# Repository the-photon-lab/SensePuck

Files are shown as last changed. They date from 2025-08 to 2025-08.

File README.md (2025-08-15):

# SensePuck / ESP32-C6 Sensor Board

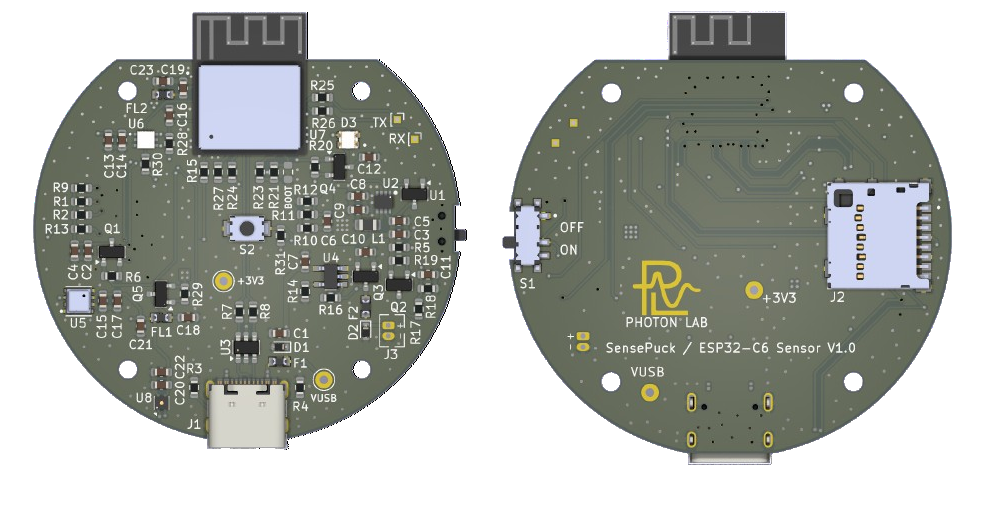
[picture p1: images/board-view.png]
SensePuck Board


**SensePuck is a compact, open-source environmental sensor board built around the ESP32-C6.** It's designed for a wide range of applications, from personal weather stations and air quality monitors to IoT data-logging projects.

---

## Key Features

-   **MCU:** **ESP32-C6-MINI-1-N4** providing Wi-Fi 6, Bluetooth 5 (LE), Zigbee, and Thread connectivity.
-   **Environmental Sensing:**
    -   **BME688:** Measures temperature, humidity, barometric pressure, and gas (Volatile Organic Compounds - VOCs).
    -   **SHT40:** High-accuracy secondary sensor for temperature and humidity.
    -   **LTR-390UV-01:** Measures both ambient light and UVA/UVB (UV Index). Includes an interrupt output for event-driven wake-ups.
-   **Flexible Power Management:**
    -   **USB-C** for charging and programming.
    -   **LiPo Battery Charger** (MCP73831T).
    -   High-efficiency **3.3V Buck Converter** (TPS62821DLCR).
    -   Physical **On/Off Power Switch**.
-   **Onboard Data Storage:** **MicroSD card slot** with card-detect switch.
-   **User Interface:**
    -   **WS2812B "NeoPixel" RGB LED** for status indication.
    -   **User-programmable tactile button**.
-   **Developer Friendly:**
    -   ESP32 Native USB connection for easy programming.
    -   Dedicated pins for initial bring-up (BOOT pins) and UART (TX/RX) for debugging.

---

## Hardware Details

The SensePuck is designed with low-power operation as a primary goal, making it ideal for long-term battery-powered deployments. This is achieved through a combination of a high-efficiency power supply, aggressive power gating of all major peripherals, and measurement circuits.

### Power Supply and Battery Management

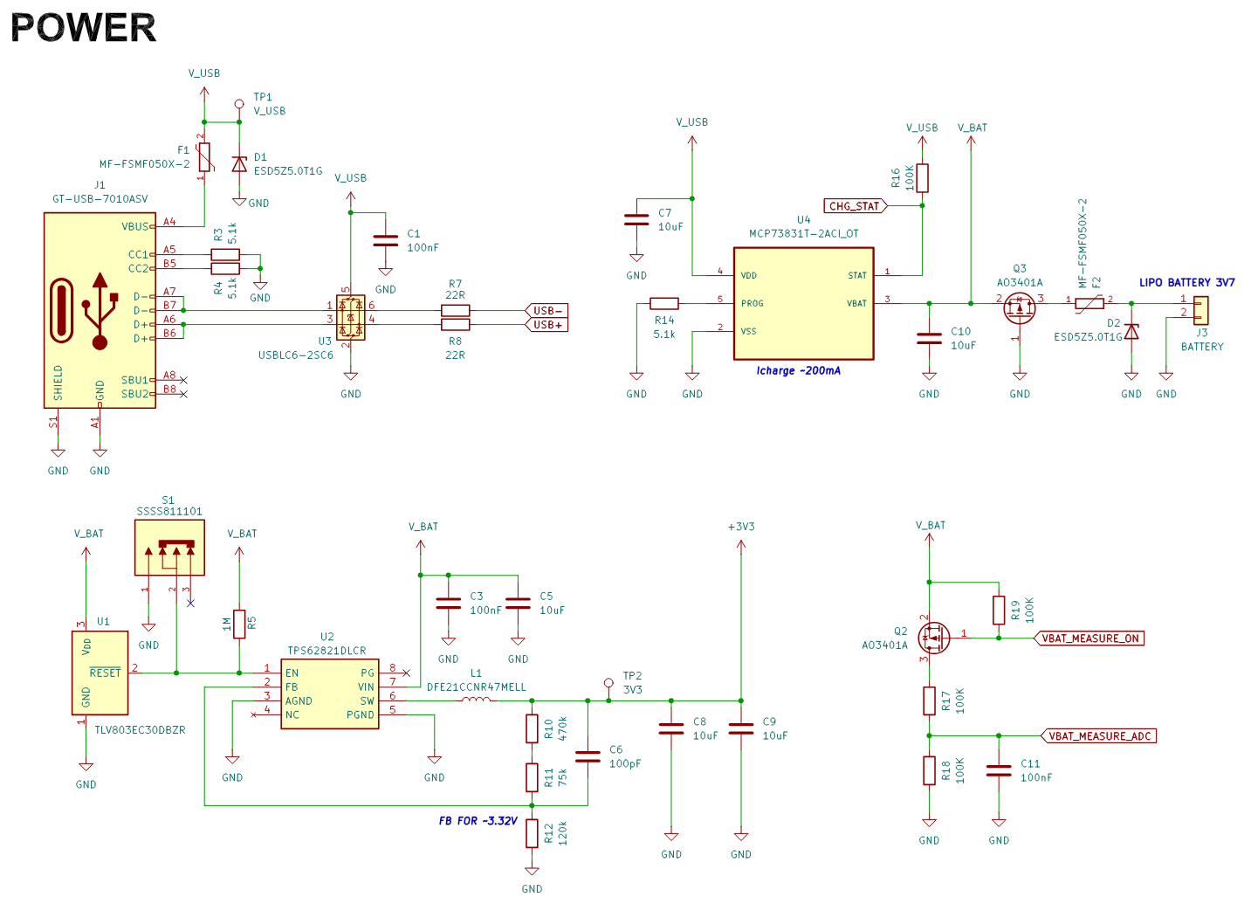
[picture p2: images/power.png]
Power Circuit


The power section is designed for efficiency, reliability, and safety in long-term battery-powered applications.

*   **Power Source:** The board is designed to be powered by a standard 3.7V single-cell LiPo battery. A physical **slide switch (S1)** serves as the master On/Off control by controlling the `ENABLE` pin of the TPS62821DLCR buck converter. For development and charging, it uses a **USB-C connector (J1)**. The USB input is protected by a **resettable fuse (F1)** and **ESD protection diodes (U3, D1)** to guard against overcurrent and electrical discharge events.

*   **Battery Charging:** The **MCP73831T (U4)** is a dedicated LiPo/Li-Ion charge management controller IC that provides reliable single-cell charging. The charge current is set to ~200mA via resistor **R14**, a conservative value suitable for a wide range of small LiPo batteries. A P-Channel MOSFET **(Q3)** provides reverse-polarity protection for the battery. The MCU can monitor the charging state (`Charging`/`Done`) via the `CHG_STAT` pin.

*   **Voltage Regulation:** The main 3.3V power supply is based on the **TPS62821DLCR (U2)**, a high-efficiency synchronous buck (step-down) converter. It takes the battery voltage and generates a stable 3.3V supply for the ESP32 and all peripherals. It offers an **extremely low quiescent current of just 60nA**, which is the tiny amount of power it consumes just by being on. This power consumption helps in achieving multi-week or multi-month battery life when the ESP32 is in deep sleep.

*   **Hardware Failsafe:** A common failure point in battery-powered devices is unstable operation when the battery voltage drops. As the battery voltage falls below 3.3V, a standard buck converter enters "dropout mode," where it can no longer regulate, and the output voltage sags along with the battery. This can cause the ESP32 to enter a "brownout" state, leading to unpredictable resets, corrupted data on the SD card, or a boot-loop that quickly kills the battery.

    To prevent this, SensePuck incorporates a **TLV803EC30DBZR (U1) voltage supervisor**.
    *   It **independently** monitors the battery voltage, completely separate from the MCU, and consumes only ~0.4µA.
    *   If the voltage drops below its fixed threshold of ~3V, the supervisor **immediately and automatically disables the buck converter** by pulling its `EN` (Enable) pin low.
    *   This forces a **clean, hard shutdown**, preventing the entire system from operating with an unstable power supply. It also serves as the main protection against over-discharging and permanently damaging the battery, even if the main firmware has crashed.

This hardware-based approach is more reliable than a software-only voltage check, which cannot prevent brownouts caused by sudden current spikes (e.g., Wi-Fi activation) or protect the battery if the software hangs.

---

### Power Gating

To achieve the lowest possible sleep current, all peripherals are completely powered off. The SensePuck uses P-Channel MOSFETs as high-side switches to disconnect power from entire circuit sections.

#### Sensor Power Control

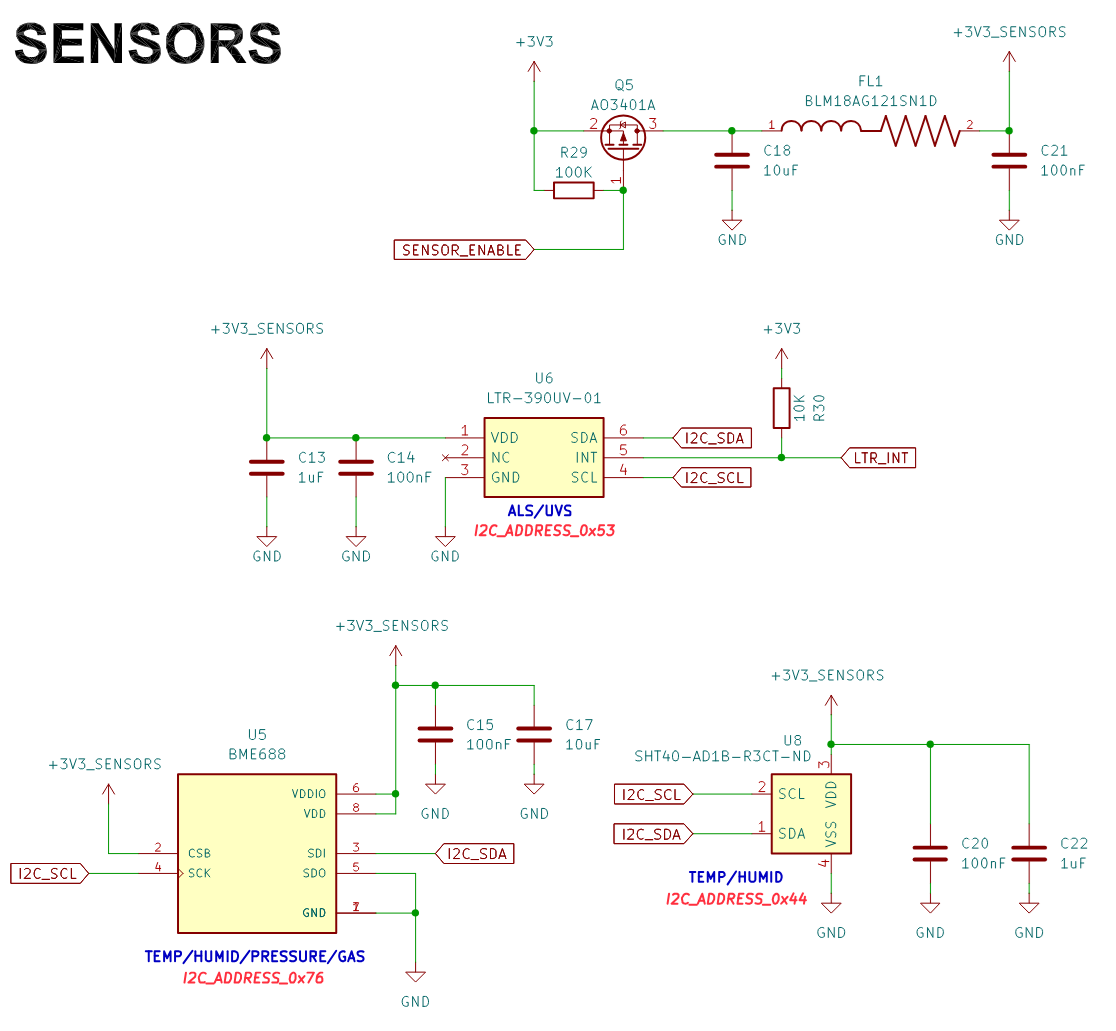
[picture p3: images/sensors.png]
Sensor Power Gating


The BME688, SHT40, and LTR-390UV sensors, while low-power, still have a quiescent current draw that would drain the battery over a few days.

*   **The Switch:** A single **P-Channel MOSFET (Q5)** controls the power rail (`+3V3_SENSORS`) for all three sensors.
*   **The Control:** The MCU's `SENSOR_ENABLE` GPIO pin controls this MOSFET.
    *   When the MCU needs to take a reading, it pulls `SENSOR_ENABLE` **LOW**. This turns the MOSFET ON, supplying power to the sensors.
    *   After the reading is complete, the MCU sets `SENSOR_ENABLE` **HIGH**. This turns the MOSFET OFF, completely cutting power to the sensors and eliminating their idle current draw.
*   **Clean Power:** A **ferrite bead (FL1)** and capacitors create a pi filter which provides extra filtering to ensure the sensors receive clean power when they are enabled, which is important for accurate measurements.

#### SD Card and RGB LED Power Control

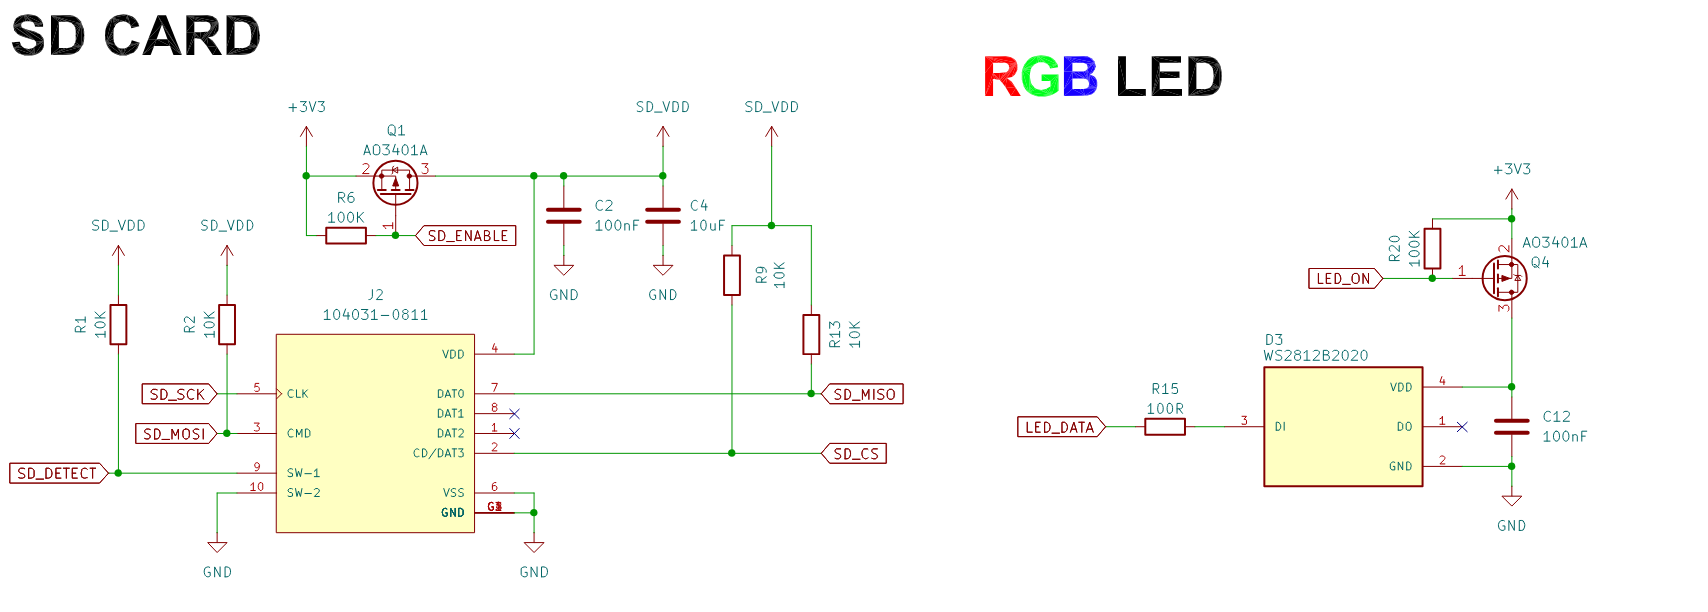
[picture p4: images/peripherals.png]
Peripheral Power Gating


This same power-gating principle is applied to the other major peripherals:

*   **SD Card:** MicroSD cards can consume significant current, even when idle. **MOSFET Q1**, controlled by the `SD_ENABLE` pin, allows the firmware to completely power down the SD card between read/write operations. The firmware can also detect if a card is present via the `SD_DETECT` pin.
*   **RGB LED:** Even the small quiescent current of the **WS2812B2020 LED (D3)** is eliminated. **MOSFET Q4**, controlled by the `LED_ON` pin, ensures the LED only receives power when it is actively being used for status indication. A 100-ohm series resistor (R15) is included to protect the data input pin and improve signal integrity.

---

### MCU and Measurement Circuits

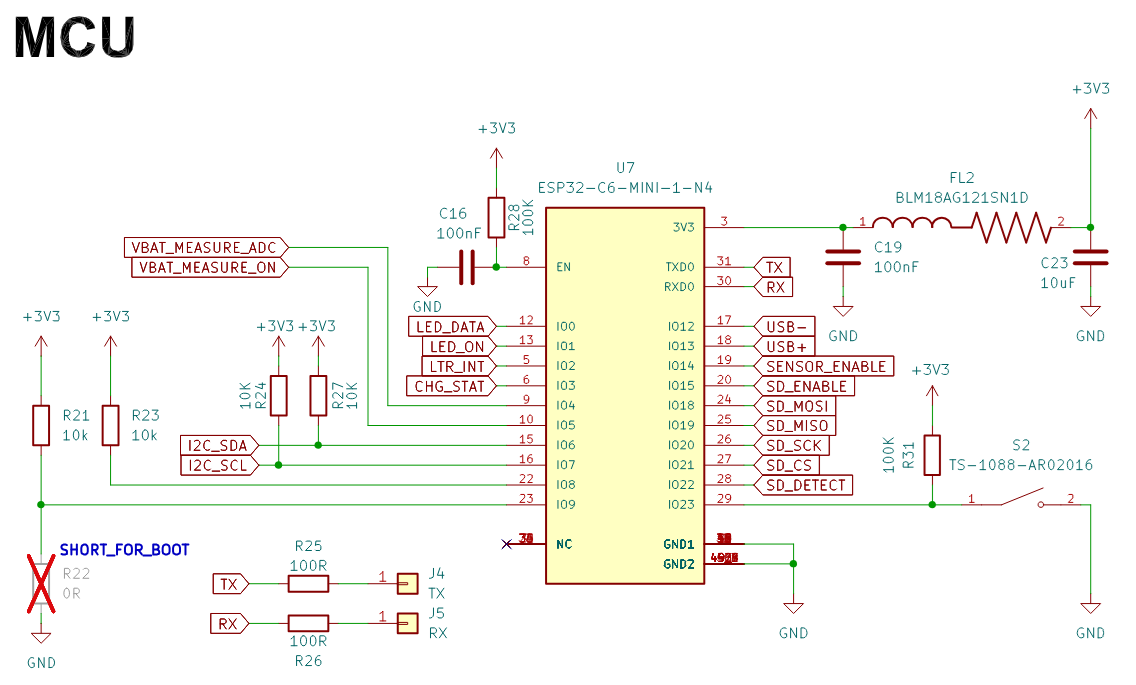
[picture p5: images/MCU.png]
MCU and Measurement Circuit


*   **ESP32-C6:** The ESP32-C6-Mini-1 is the "brain" of the board. Its primary low-power feature is its ultra deep-sleep mode, where the main cores and most peripherals are shut down, allowing the chip to run on mere microamps of current while waiting for a timer or external trigger to wake up. Its power supply is further stabilized with a dedicated ferrite bead filter (FL2).
*   **Power-Gated Battery Measurement:** Measuring the battery level without constantly draining it is a common challenge. SensePuck solves this with the following circuit:
    1.  A voltage divider (**R17** and **R18**) is used to scale the battery voltage down to a level that is safe for the ESP32's ADC.
    2.  Crucially, this divider is **not** permanently connected to the battery. A **MOSFET (Q2)** acts as a switch at the top of the divider.
    3.  To check the battery, the firmware momentarily pulls the `VBAT_MEASURE_ON` pin low, which turns on Q2, completes the circuit, and allows for an ADC reading. It then immediately turns Q2 off.
    4.  This ensures the voltage divider only draws current for the few milliseconds required to take a measurement, making the process extremely energy efficient.

---

### Component & Pinout Overview

#### Key Components

| Reference | Component | Description | I2C Address |
| :--- | :--- | :--- | :--- |
| U7 | ESP32-C6-MINI-1-N4 | Main Microcontroller with Wi-Fi 6, BT5, Zigbee, Thread | - |
| U5 | BME688 | Temperature, Humidity, Pressure & Gas (VOC) Sensor | `0x76` |
| U8 | SHT40-AD1B-R3CT-ND | High-Precision Temperature & Humidity Sensor | `0x44` |
| U6 | LTR-390UV-01 | Ambient Light & UV Sensor | `0x53` |
| U4 | MCP73831T-2ACI_OT | Li-Ion/Li-Polymer Battery Charge Management Controller | - |
| U2 | TPS62821DLCR | High-Efficiency 3.3V Step-Down Converter | - |
| J2 | 104031-0811 | MicroSD Card Socket | - |
| D3 | WS2812B2020 | Addressable RGB LED for status indication | - |

#### ESP32-C6 Pinout

| ESP32-C6 Pin | GPIO | Function | Schematic Net Name | Notes |
| :--- | :--- | :--- | :--- | :--- |
| 12 | IO0  | LED Data | `LED_DATA` | Data line for WS2812B RGB LED |
| 13 | IO1  | LED Power Enable | `LED_ON` | `LOW` = On, `HIGH` = Off |
| 5 | IO2  | LTR-390UV Interrupt | `LTR_INT` | Active-low interrupt from light sensor |
| 6 | IO3  | Charger Status Read | `CHG_STAT` | `LOW` = Charging, `HIGH`/`Z` = Done |
| 9 | IO4  | Battery Measurement ADC | `VBAT_MEASURE_ADC` | ADC input for battery voltage |
| 10 | IO5  | Battery Measurement Enable  | `VBAT_MEASURE_ON` | `LOW` = On, `HIGH` = Off |
| 15 | IO6  | I2C Data | `I2C_SDA` | Sensor I2C Bus |
| 16 | IO7  | I2C Clock | `I2C_SCL` | Sensor I2C Bus |
| 23 | IO9  | User Button / Boot | - | General purpose button |
| 19 | IO14 | Sensor Power Enable | `SENSOR_ENABLE` | `LOW` = On, `HIGH` = Off |
| 20 | IO15 | SD Card Power Enable | `SD_ENABLE` | `LOW` = On, `HIGH` = Off |
| 24 | IO18 | SPI MOSI for SD Card | `SD_MOSI` | |
| 25 | IO19 | SPI MISO for SD Card | `SD_MISO` | |
| 26 | IO20 | SPI Clock for SD Card | `SD_SCK` | |
| 27 | IO21 | SPI Chip Select for SD Card | `SD_CS` | |
| 28 | IO22 | SD Card Detect | `SD_DETECT` | `LOW` when card is inserted |

---

## Firmware

**Coming Soon!**

The firmware for the SensePuck is currently under development. It will be built using the ESP-IDF framework for complete control of the MCU's peripherals to ensure ultra-low power operation.

### Board Bring-Up

*   **Entering Bootloader Mode:** To flash the board for the first time, you must put the ESP32-C6 into bootloader mode. Short circuit the **BOOT** pads, connect the USB-C cable, and then release.
*   **Debugging:** The headers J4 (TX) and J5 (RX) expose the ESP32-C6's primary hardware UART. This can be used with an external USB-to-Serial adapter for low-level debugging.

This board is also compatible with ESPHome. YAML Configuration will be provided soon.

---

## License

This project is open source hardware, licensed under the **CERN Open Hardware Licence Version 2 - Permissive (CERN-OHL-P v2)**.

You are welcome to use, modify, manufacture, and distribute this hardware design, provided you give credit to the original author and include the original copyright and license notice. For the full license details, please see the `LICENSE` file included in this repository.

A `NOTICE` file with licensor and project details is also included, as required by the license.

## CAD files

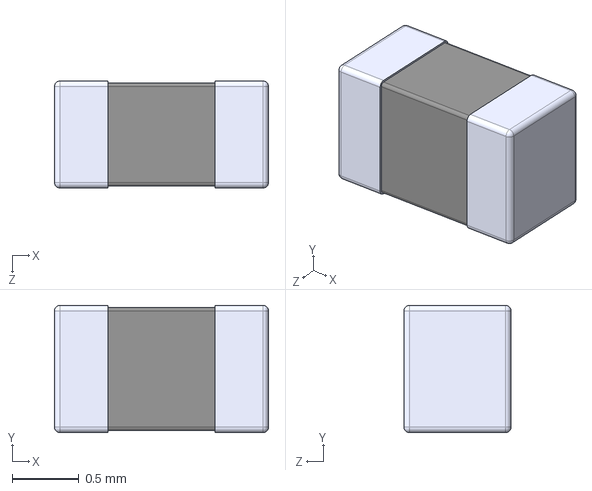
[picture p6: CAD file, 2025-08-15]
libraries-zips/BLM18AG121SN1D/BLM18AG121SN1D.step
1.60 x 0.95 x 0.8 mm

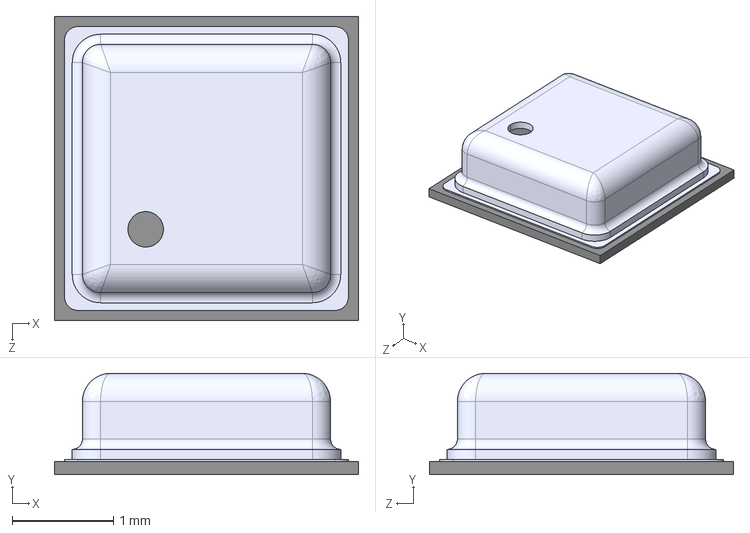
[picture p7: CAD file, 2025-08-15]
libraries-zips/BME688/BME688.step
3.00 x 1.00 x 3.00 mm

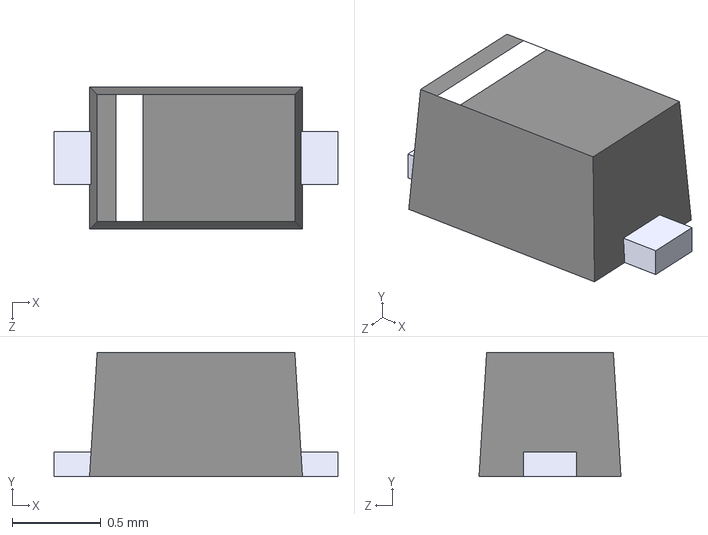
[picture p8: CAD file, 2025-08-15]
libraries-zips/ESD5Z5.0T1G/ESD5Z5.0T1G.step
1.60 x 0.7 x 0.8 mm

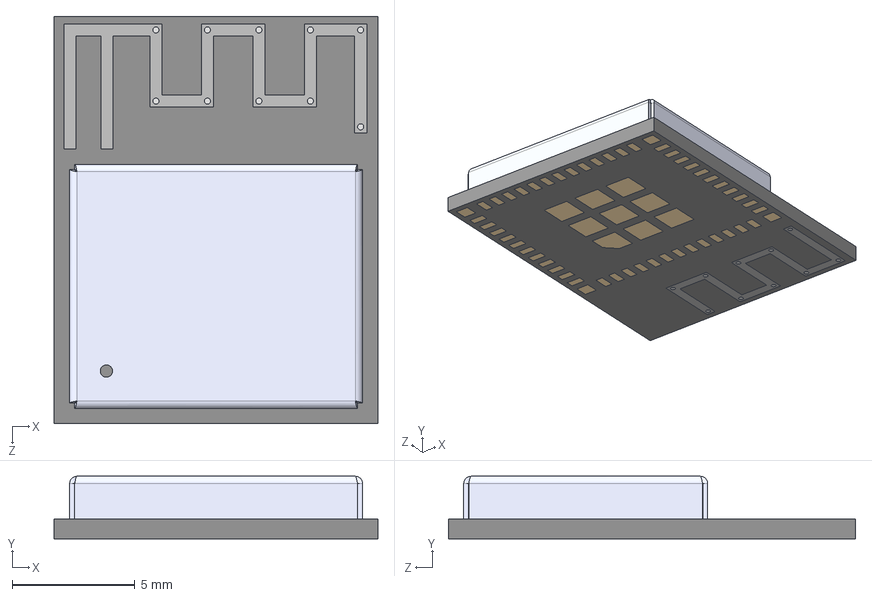
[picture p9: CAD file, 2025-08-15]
libraries-zips/ESP32-C6-MINI-1-N4/ESP32-C6-MINI-1-N4.STEP
13.2 x 2.55 x 16.6 mm

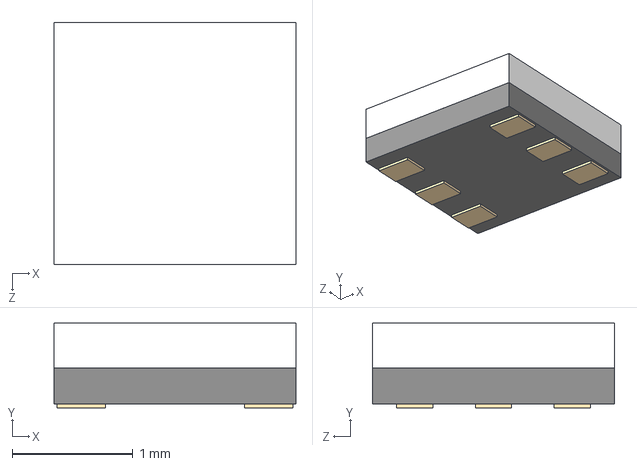
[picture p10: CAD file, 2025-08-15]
libraries-zips/LIB_LTR-390UV-01/LTR-390UV-01/KiCad/LTR-390UV-01.step
2.00 x 0.7 x 2.00 mm

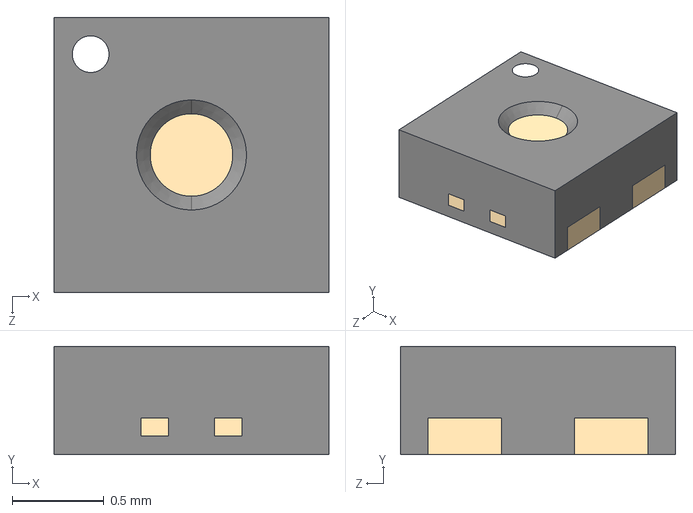
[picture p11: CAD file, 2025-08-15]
libraries-zips/SHT4XI-DIGITAL/SHT4XI-DIGITAL.step
1.50 x 0.59 x 1.50 mm

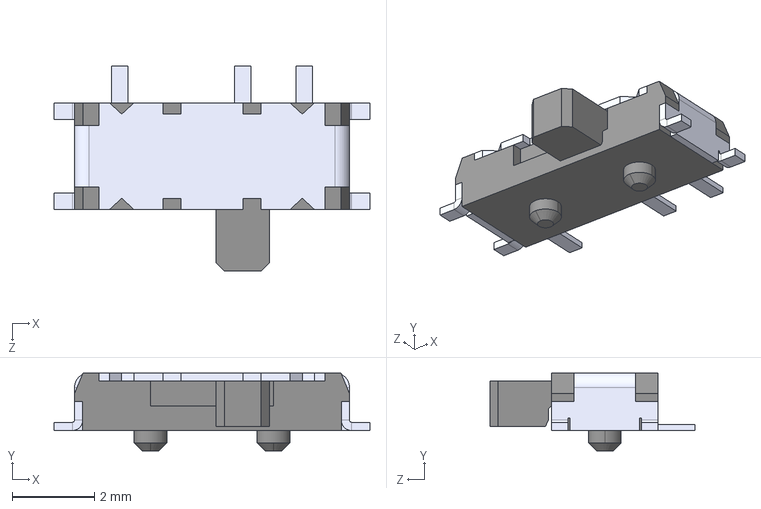
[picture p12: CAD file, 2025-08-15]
libraries-zips/SSSS811101/SSSS811101.step
7.70 x 1.90 x 5.00 mm

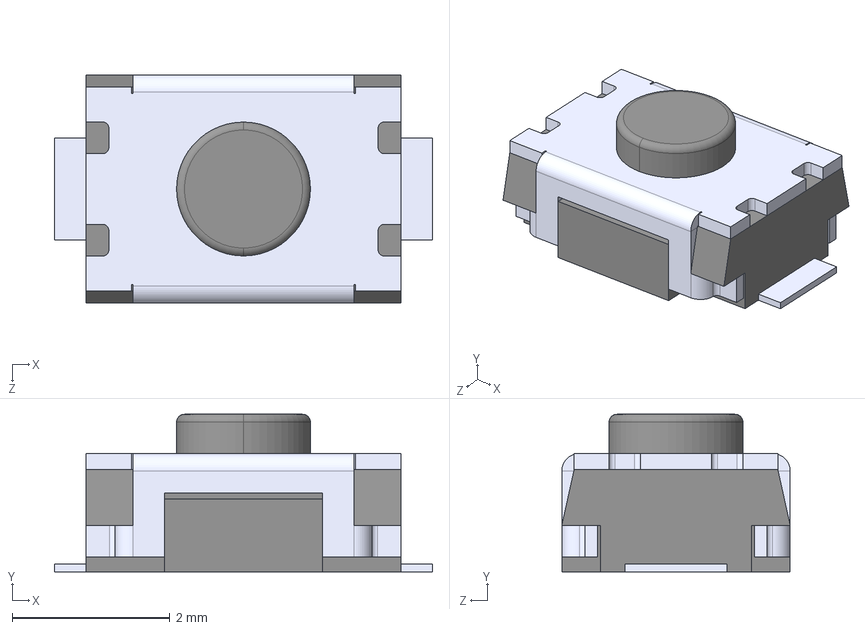
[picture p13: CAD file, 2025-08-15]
libraries-zips/TS-1088-AR02016/TS-1088-AR02016.step
4.80 x 2.00 x 2.90 mm

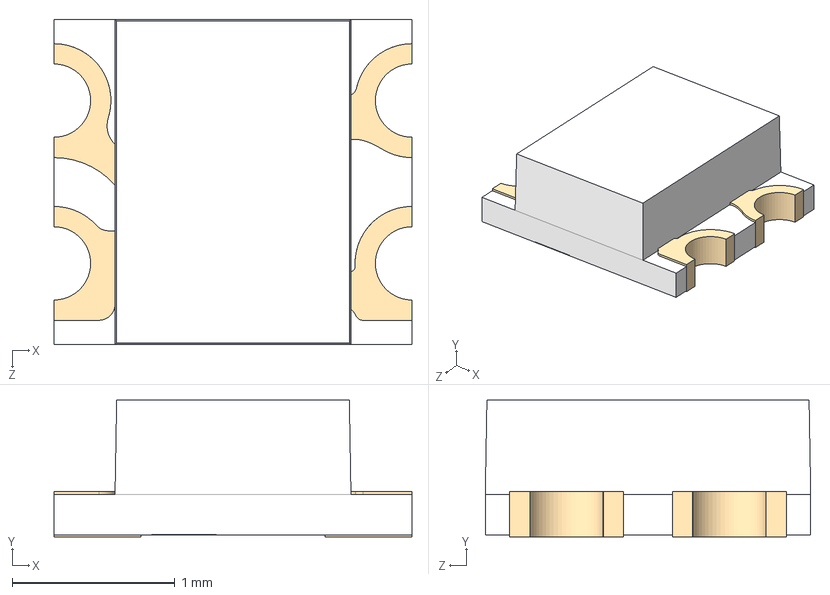
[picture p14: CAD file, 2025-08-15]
libraries-zips/WS2812B2020/WS2812B2020.step
2.20 x 0.84 x 2.00 mm

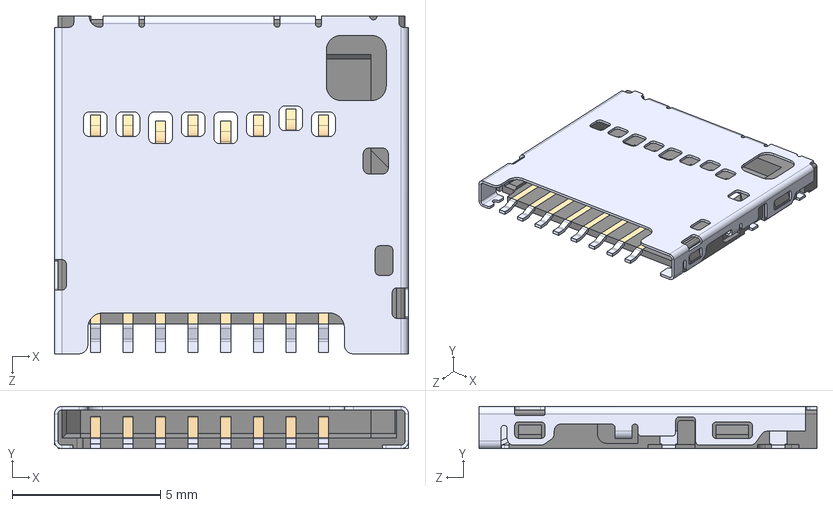
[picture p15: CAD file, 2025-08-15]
libraries-zips/104031-0811/104031-0811.step
12.0 x 1.42 x 11.4 mm

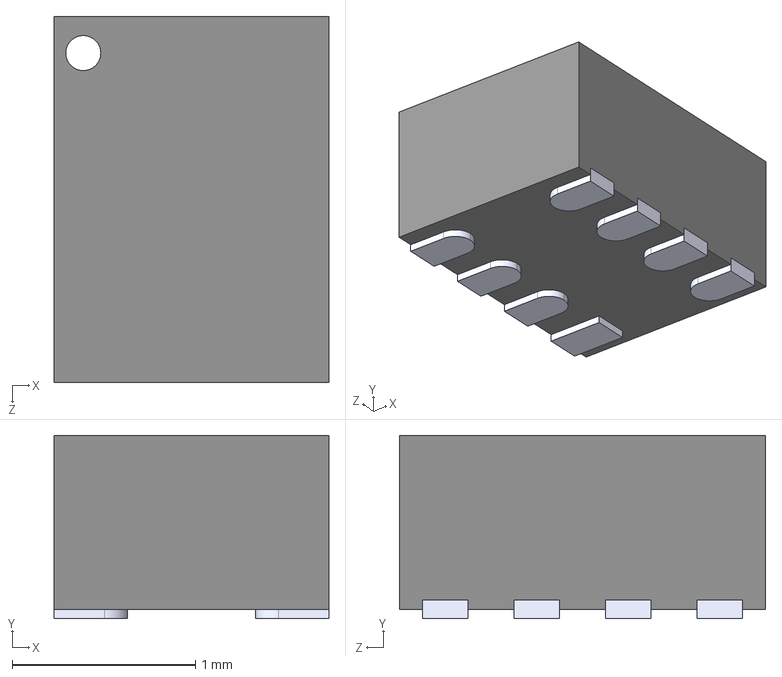
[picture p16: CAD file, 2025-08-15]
libraries-zips/LIB_TPS62821DLCR/TPS62821DLCR.STEP
1.50 x 1.00 x 2.00 mm

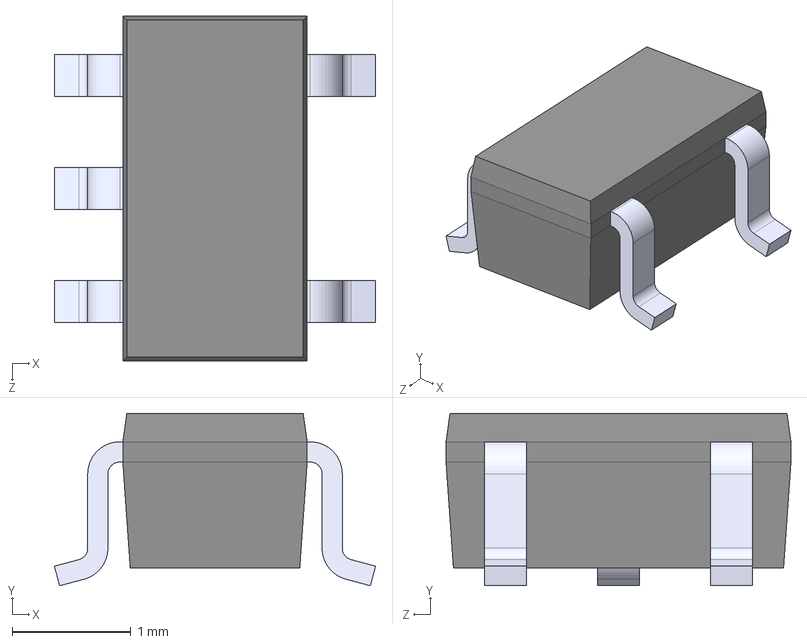
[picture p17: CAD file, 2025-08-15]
libraries-zips/MCP73831T-2ACI_OT/MCP73831T-2ACI_OT.STEP
2.70 x 1.45 x 2.90 mm

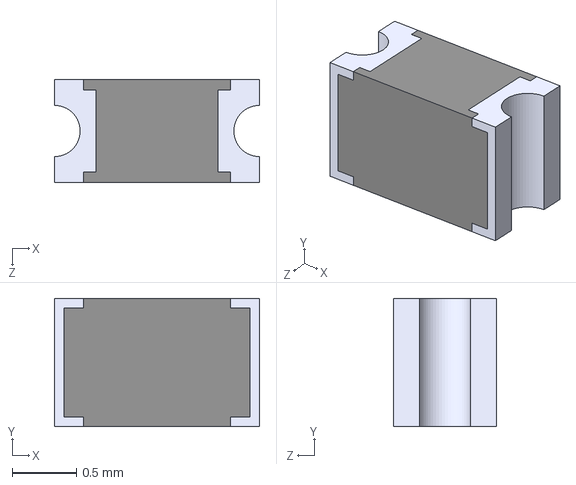
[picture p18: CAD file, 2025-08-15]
libraries-zips/MF-FSMF050X-2/0603L300SLYR--3DModel-STEP-510211.STEP
1.60 x 1.00 x 0.8 mm

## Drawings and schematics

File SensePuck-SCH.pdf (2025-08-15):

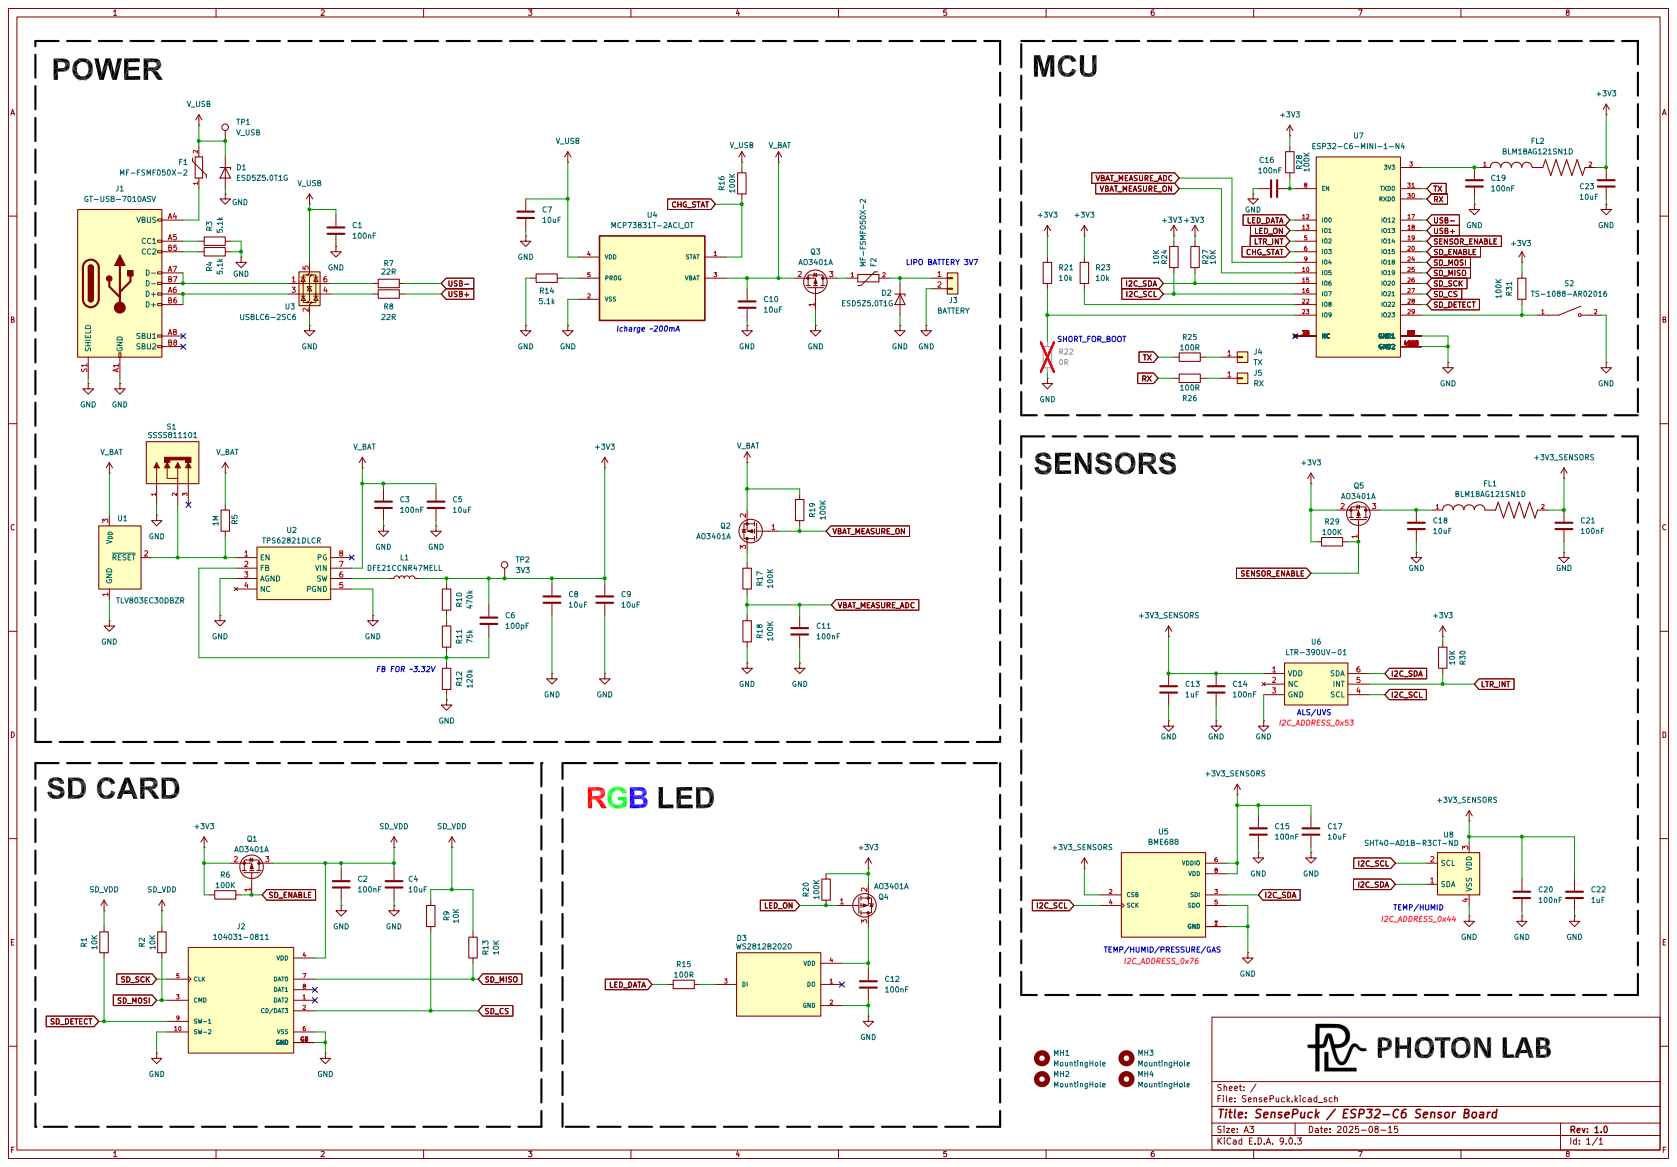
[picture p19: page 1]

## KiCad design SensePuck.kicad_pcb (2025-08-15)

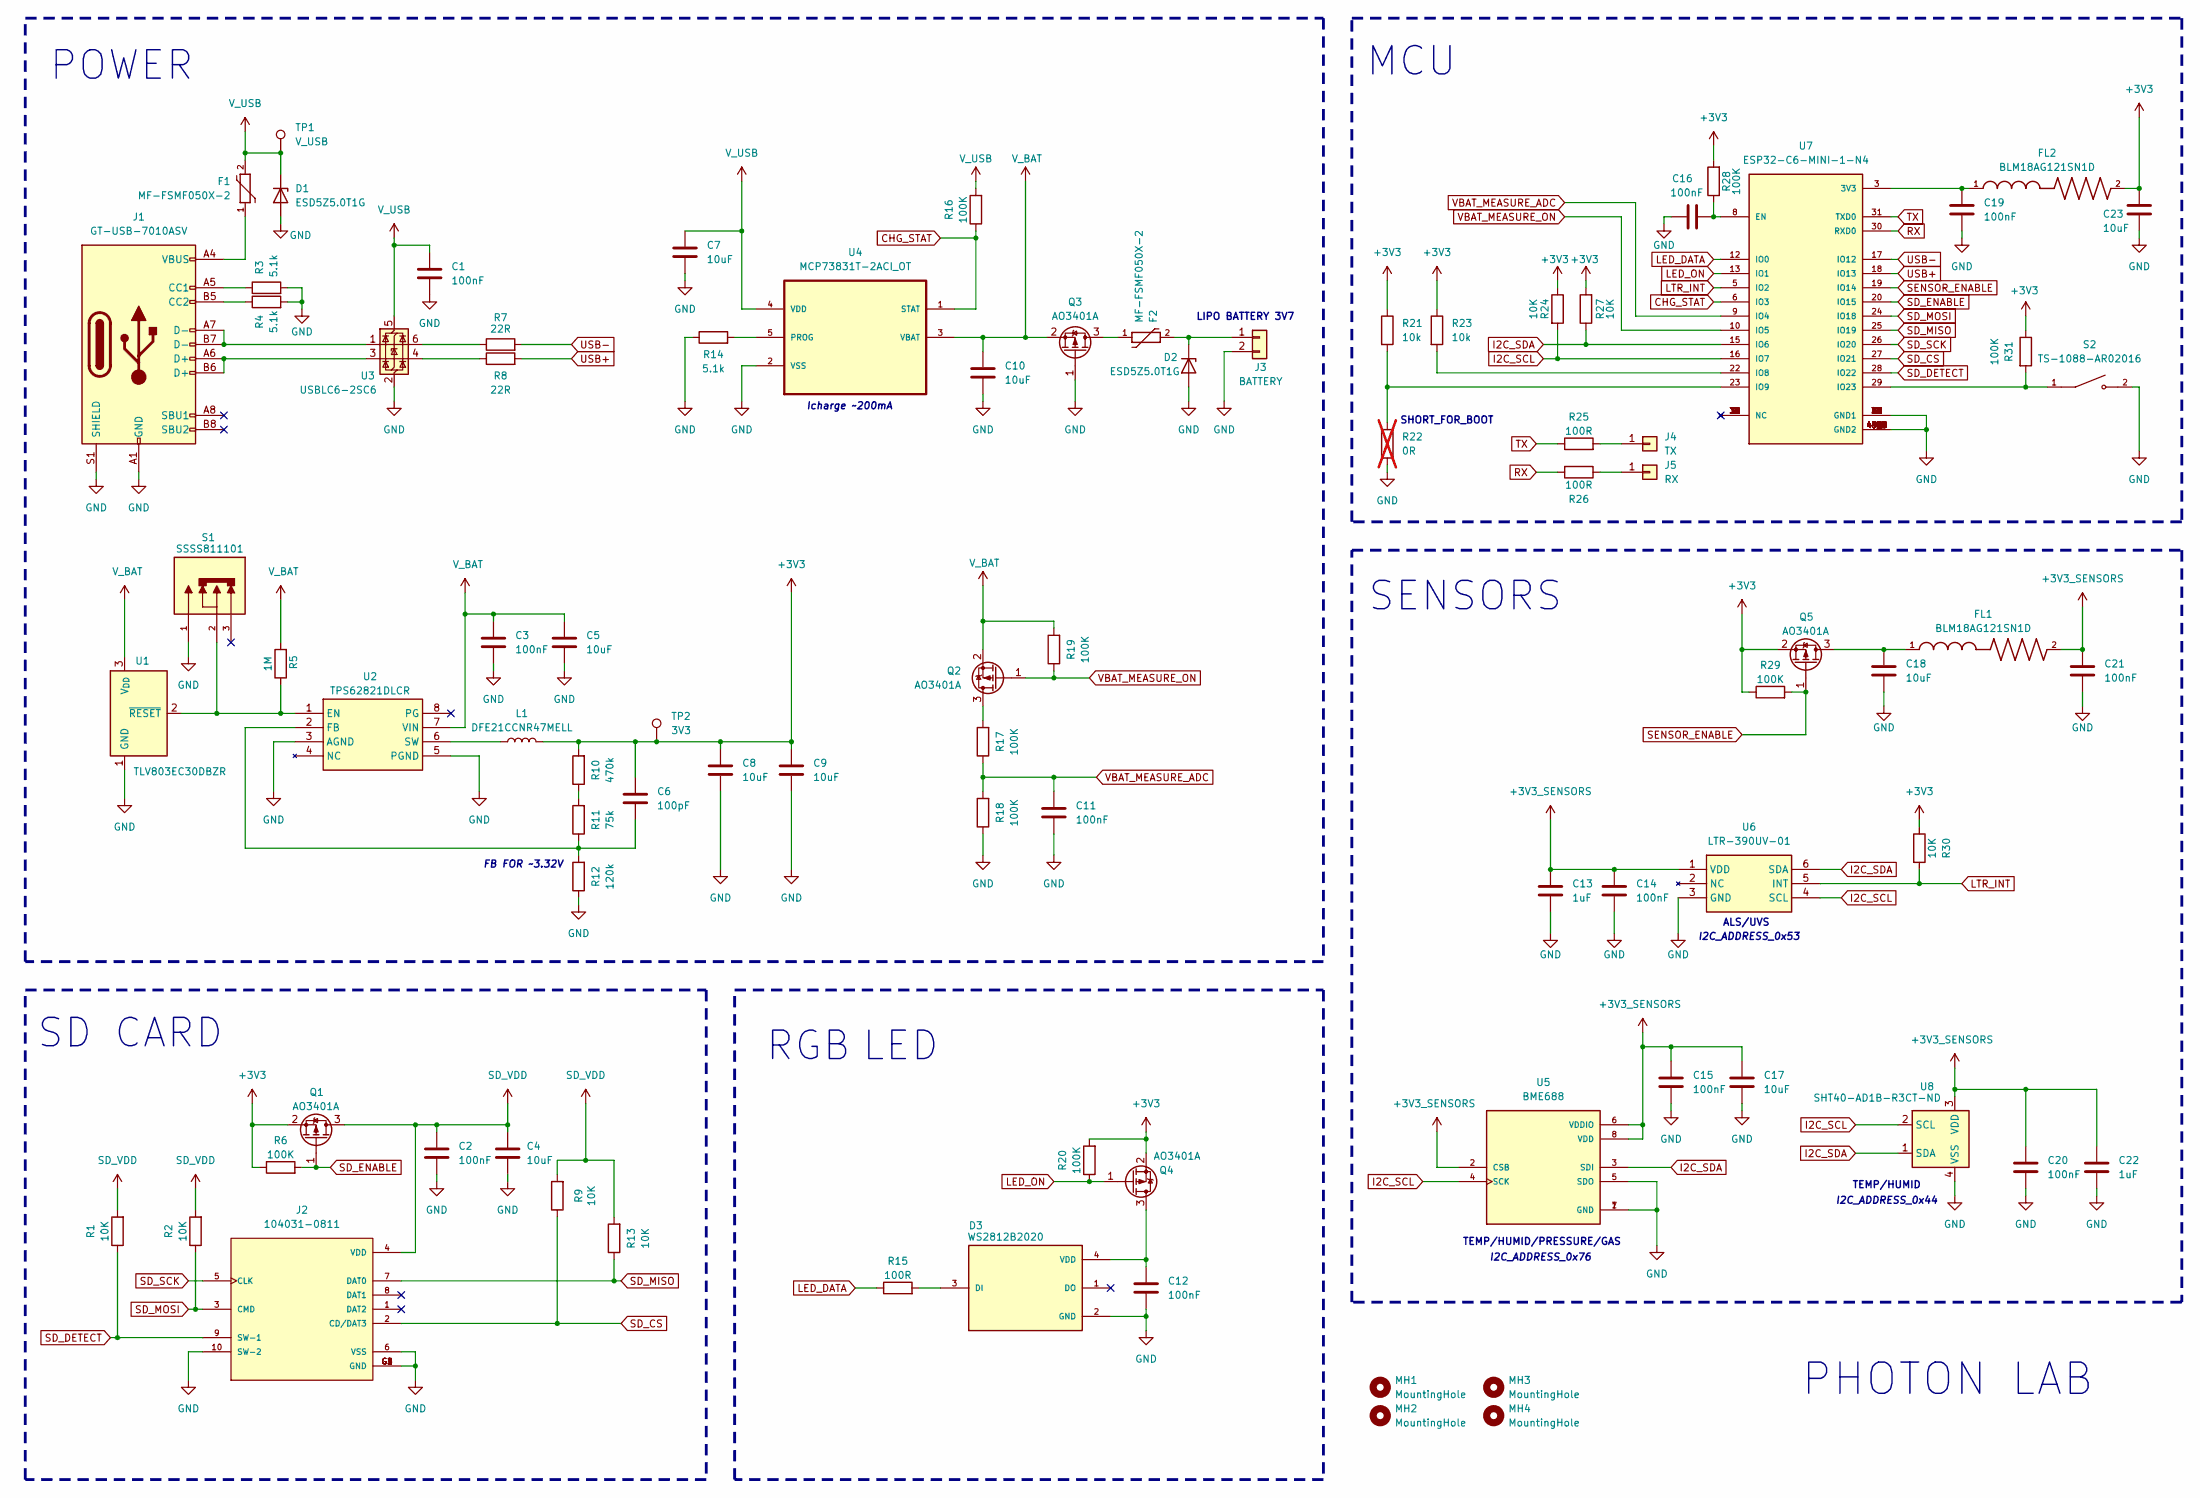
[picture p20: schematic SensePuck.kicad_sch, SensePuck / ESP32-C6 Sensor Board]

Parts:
C1, C2, C3, C11, C12, C14, C15, C16, C19, C20, C21: 100nF; C_0603_1608Metric
C4, C5, C7, C8, C9, C10, C17, C18, C23: 10uF; C_0603_1608Metric
C6: 100pF; C_0603_1608Metric
C13, C22: 1uF; C_0603_1608Metric
D1, D2: ESD5Z5.0T1G; D_SOD-523
D3: WS2812B2020; LED_WS2812B2020; PARTREV V1.0
F1, F2: MF-FSMF050X-2; 0603-F1608X100N; MPN MF-FSMF050X-2
FL1, FL2: BLM18AG121SN1D; BEADC1608X95N
J1: GT-USB-7010ASV; USB_C_Receptacle_G-Switch_GT-USB-7010ASV
J2: 104031-0811; MOLEX_104031-0811; PARTREV B2
J3: BATTERY; Hirose_DF13-02P-1.25DSA_1x02_P1.25mm_Vertical
J4: TX; PinHeader_1x01_P1.00mm_Vertical
J5: RX; PinHeader_1x01_P1.00mm_Vertical
L1: DFE21CCNR47MELL; L_0805_2012Metric
MH1, MH2, MH3, MH4: MountingHole; MountingHole_2.2mm_M2
Q1, Q2, Q3, Q4, Q5: AO3401A; SOT-23
R1, R2, R9, R13, R24, R27, R30: 10K; R_0603_1608Metric
R3, R4, R14: 5.1k; R_0603_1608Metric
R5: 1M; R_0603_1608Metric
R6, R16, R17, R18, R19, R20, R28, R29, R31: 100K; R_0603_1608Metric
R7, R8: 22R; R_0603_1608Metric
R10: 470k; R_0603_1608Metric
R11: 75k; R_0603_1608Metric
R12: 120k; R_0603_1608Metric
R15, R25, R26: 100R; R_0603_1608Metric
R21, R23: 10k; R_0603_1608Metric
R22: 0R; R_0603_1608Metric; not fitted
S1: SSSS811101; SW_SSSS811101; PARTREV N/A
S2: TS-1088-AR02016; SW_TS-1088-AR02016; PARTREV N/A
TP1: V_USB; Pin_D1.0mm_L10.0mm
TP2: 3V3; Pin_D1.0mm_L10.0mm
U1: TLV803EC30DBZR; SOT-23-3
U2: TPS62821DLCR; SON50P150X200X100-8N; Mouser Part Number 595-TPS62821DLCR
U3: USBLC6-2SC6; SOT-23-6
U4: MCP73831T-2ACI_OT; SOT95P280X145-5N; MPN MCP73831T-2ACI/OT
U5: BME688; IC_BME688; PARTREV 1.0
U6: LTR-390UV-01; Mouser Part Number 859-LTR390UV01
U7: ESP32-C6-MINI-1-N4; XCVR_ESP32-C6-MINI-1-N4; PARTREV 1.0
U8: SHT40-AD1B-R3CT-ND; Sensirion_DFN-4_1.5x1.5mm_P0.8mm_SHT4x_NoCentralPad

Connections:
+3V3: C6.1, C8.1, C9.1, C23.1, FL2.2, L1.2, Q1.2 (S), Q4.2 (S), Q5.2 (S), R6.1, R10.2, R20.2, R21.1, R23.1, R24.1, R27.2, R28.2, R29.1, R30.1, R31.1, TP2.1
+3V3_SENSORS: C13.1, C14.1, C15.1, C17.1, C20.1, C21.1, C22.1, FL1.2, U5.2 (CSB), U5.6 (VDDIO), U5.8 (VDD), U6.1 (VDD), U8.3 (VDD)
CHG_STAT: R16.1, U4.1 (STAT), U7.6 (IO3)
GND: C1.2, C2.2, C3.2, C4.2, C5.2, C7.2, C8.2, C9.2, C10.2, C11.2, C12.2, C13.2, C14.2, C15.2, C16.1, C17.2, C18.2, C19.2, C20.2, C21.2, C22.2, C23.2, D1.2 (A), D2.2 (A), D3.2 (GND), J1.A1 (GND), J1.A12 (GND), J1.B1 (GND), J1.B12 (GND), J1.S1 (SHIELD), J2.6 (VSS), J2.10 (SW-2), J2.G1 (GND), J2.G2 (GND), J2.G3 (GND), J2.G4 (GND), J3.2, Q3.1 (G), R3.2, R4.2, R12.1, R14.1, R18.1, R22.2, S1.1, S2.2, U1.1 (GND), U2.3 (AGND), U2.5 (PGND), U3.2 (GND), U4.2 (VSS), U5.1 (GND), U5.5 (SDO), U5.7 (GND), U6.3 (GND), U7.1 (GND1), U7.2 (GND1), U7.11 (GND1), U7.14 (GND1), U7.36 (GND1), U7.37 (GND1), U7.38 (GND1), U7.39 (GND1), U7.40 (GND1), U7.41 (GND1), U7.42 (GND1), U7.43 (GND1), U7.44 (GND1), U7.45 (GND1), U7.46 (GND1), U7.47 (GND2), U7.48 (GND2), U7.49_1 (GND2), U7.49_2 (GND2), U7.49_3 (GND2), U7.49_4 (GND2), U7.49_5 (GND2), U7.49_6 (GND2), U7.49_7 (GND2), U7.49_8 (GND2), U7.49_9 (GND2), U7.50 (GND2), U7.51 (GND2), U7.52 (GND2), U7.53 (GND2), U8.4 (VSS); also elsewhere on the board
I2C_SCL: R24.2, U5.4 (SCK), U6.4 (SCL), U7.16 (IO7), U8.2 (SCL)
I2C_SDA: R27.1, U5.3 (SDI), U6.6 (SDA), U7.15 (IO6), U8.1 (SDA)
LED_DATA: R15.1, U7.12 (IO0)
LED_ON: Q4.1 (G), R20.1, U7.13 (IO1)
LTR_INT: R30.2, U6.5 (INT), U7.5 (IO2)
unnamed: D2.1 (K), F2.2, J3.1
unnamed: D3.3 (DI), R15.2
unnamed: C12.1, D3.4 (VDD), Q4.3 (D)
unnamed: F1.1, J1.A4 (VBUS), J1.A9 (VBUS), J1.B4 (VBUS), J1.B9 (VBUS)
unnamed: J1.A5 (CC1), R3.1
unnamed: J1.B5 (CC2), R4.1
unnamed: J1.A6 (D+), J1.B6 (D+), U3.3 (I/O2)
unnamed: J1.A7 (D-), J1.B7 (D-), U3.1 (I/O1)
unnamed 17: J4.1, R25.2; also elsewhere on the board
unnamed 18: J5.1, R26.1; also elsewhere on the board
unnamed: Q2.3 (D), R17.2
unnamed: F2.1, Q3.3 (D)
unnamed: C18.1, FL1.1, Q5.3 (D)
unnamed: R7.1, U3.6 (I/O1)
unnamed: R8.1, U3.4 (I/O2)
unnamed: R10.1, R11.2
unnamed: R5.1, S1.2, U1.2 (~RESET), U2.1 (EN)
unnamed: C6.2, R11.1, R12.2, U2.2 (FB)
unnamed: L1.1, U2.6 (SW)
unnamed: R14.2, U4.5 (PROG)
unnamed: C19.1, FL2.1, U7.3 (3V3)
unnamed: C16.2, R28.1, U7.8 (EN)
unnamed: R23.2, U7.22 (IO8)
unnamed 32: R21.2, R22.1, U7.23 (IO9); also elsewhere on the board
unnamed: R31.2, S2.1, U7.29 (IO23)
RX: R26.2, U7.30 (RXD0)
SD_CS: J2.2 (CD/DAT3), R9.1, U7.27 (IO21)
SD_DETECT: J2.9 (SW-1), R1.1, U7.28 (IO22)
SD_ENABLE: Q1.1 (G), R6.2, U7.20 (IO15)
SD_MISO: J2.7 (DAT0), R13.1, U7.25 (IO19)
SD_MOSI: J2.3 (CMD), R2.1, U7.24 (IO18)
SD_SCK: J2.5 (CLK), U7.26 (IO20)
SD_VDD: C2.1, C4.1, J2.4 (VDD), Q1.3 (D), R1.2, R2.2, R9.2, R13.2
SENSOR_ENABLE: Q5.1 (G), R29.2, U7.19 (IO14)
TX: R25.1, U7.31 (TXD0)
USB+: R8.2, U7.18 (IO13)
USB-: R7.2, U7.17 (IO12)
VBAT_MEASURE_ADC: C11.1, R17.1, R18.2, U7.9 (IO4)
VBAT_MEASURE_ON: Q2.1 (G), R19.1, U7.10 (IO5)
V_BAT: C3.1, C5.1, C10.1, Q2.2 (S), Q3.2 (S), R5.2, R19.2, U1.3 (V_{DD}), U2.7 (VIN), U4.3 (VBAT)
V_USB: C1.1, C7.1, D1.1 (K), F1.2, R16.2, TP1.1, U3.5 (VBUS), U4.4 (VDD); also elsewhere on the board

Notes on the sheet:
TEMP/HUMID/PRESSURE/GAS
POWER
FB FOR ~3.32V
I2C_ADDRESS_0x76
I2C_ADDRESS_0x53
SD CARD
SHORT_FOR_BOOT
LED
PHOTON LAB
LIPO BATTERY 3V7
I2C_ADDRESS_0x44
ALS/UVS
MCU
Icharge ~200mA
TEMP/HUMID
SENSORS

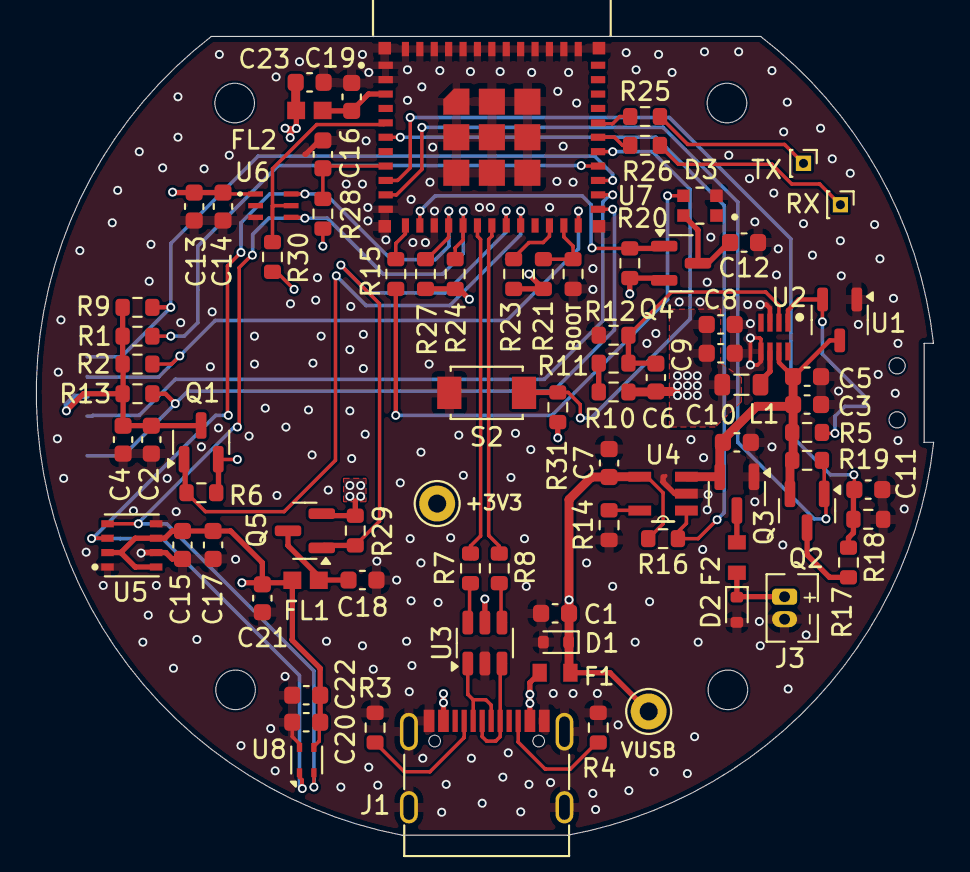
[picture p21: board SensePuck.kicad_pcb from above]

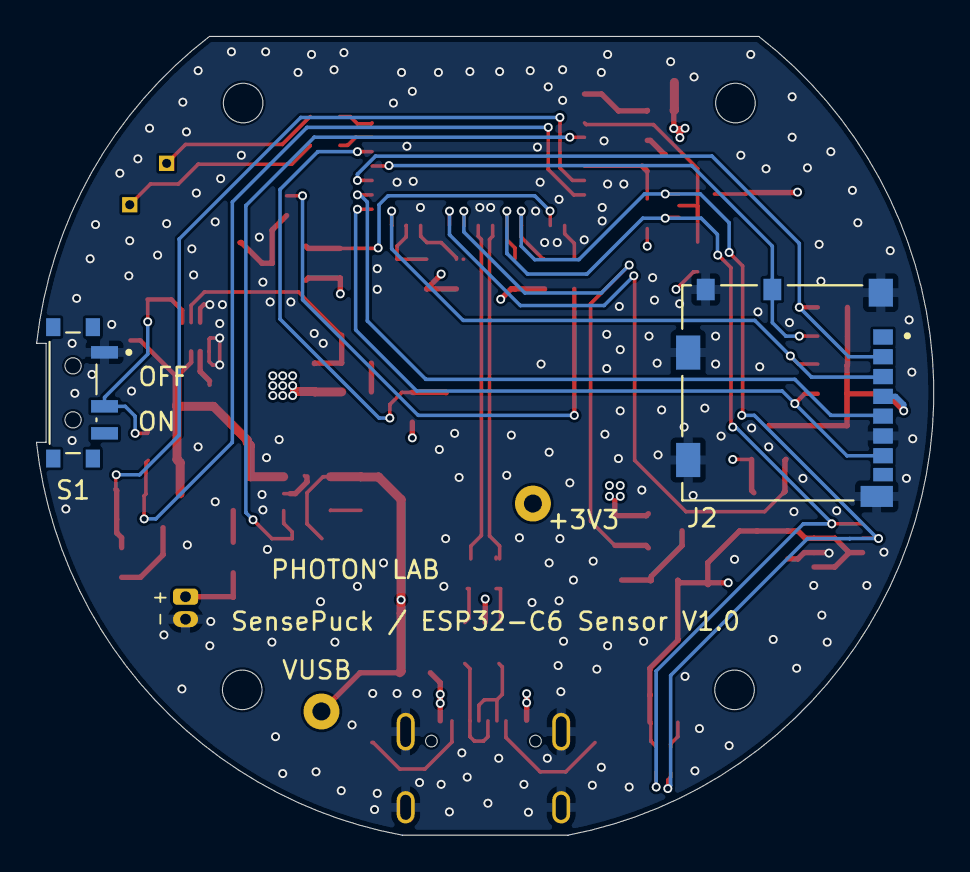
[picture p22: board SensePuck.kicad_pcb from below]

Board: 4 copper layers, 49.8 x 44.4 mm, 88 parts (2 on the bottom side), 50 nets.

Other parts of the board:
+3V3: 3V3; Pin_D1.0mm_L10.0mm
BOOT: 0R; R_0603_1608Metric
RX: RX; PinHeader_1x01_P1.00mm_Vertical
TX: TX; PinHeader_1x01_P1.00mm_Vertical
VUSB: V_USB; Pin_D1.0mm_L10.0mm

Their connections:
GND: BOOT.2; also elsewhere on the board
unnamed 17: TX.1; also elsewhere on the board
unnamed 18: RX.1; also elsewhere on the board
unnamed 32: BOOT.1; also elsewhere on the board
V_USB: VUSB.1; also elsewhere on the board
